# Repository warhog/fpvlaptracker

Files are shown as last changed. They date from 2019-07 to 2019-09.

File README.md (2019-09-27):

# fpvlaptracker

master: 

dev: 

licensed under [MIT](LICENSE.md)

open source diy fpv vtx lap tracking system

## features
- uses your analog vtx to do the lap detection
- 48 channels supported
- standalone (app) or connected mode (web frontend) available for single practicing or fun with friends
- connected mode supports up to 8 tracker units and comfortable access using web ui
- 2ms accuracy (tested with 4 parallel nodes)

## how does it work?
the tracker unit measures the video signal strength (rssi) of the selected video channel to detect laps using peak detection. it has a stand alone mode for single participants or a connected mode supporting multiple participants and a web ui. in standalone mode the tracker unit is controlled using bluetooth and a mobile app for configuration and single user race (e.g. practicing). the connected mode is used with any hardware that can run the java software backend.

### app
the tracker unit is accessed using bluetooth and a mobile application (older version was creating an wifi ap and serving a webpage but that was horrible slow). using the app one can configure the unit or run single user races (e.g. practicing).

the application is available in the play store (only android right now, [play store](https://play.google.com/store/apps/details?id=de.warhog.fpvlaptracker)), the source is in the app folder).

### standalone mode
the tracker can be used in standalone mode for single user races. only one tracker node and the app is needed.

### connected mode
running in the connected mode the tracker connects to a host software using wifi. races and particpants can be organized inside the host software. the host software includes a webserver that serves a web ui for watching / controlling races. one to multiple (max. 8) tracker nodes and server with wifi (e.g. raspi) required.

## tested devices
* immersion rc vtx
* blade inductrix fpv
* boscam ts5828
* eachine et526
* tbs unify pro hv
* betafpv 75s

## setup
[setup instructions](docs/setup.md)
    
## which hardware and software is used?
the hardware consists of a esp32 board with a boscam rx5808 receiver module connected. the esp32 runs the tracker firmware (written using Arduino software platform).
the backend of the race software for connected mode was written in java using spring boot 2. the frontend was developed using angular 8. the race software can be run on almost every platform that supports java se.
due to the low price, simplicity and size a raspberry pi (>= 2) powered by a power bank is the optimum solution for mobile usage.

# repository information
this repository contains everything needed to build your own tracker(s).

* app: the mobile app
* firmware: firmware for a single node
* hardware: hardware for a single node
* web: the java backend and web frontend for multiple node races

## sound files used
_lap:_ [freesound](https://www.freesound.org/people/StaneStane/sounds/73560/)

texts: [fromtexttospeech.com](http://www.fromtexttospeech.com/)

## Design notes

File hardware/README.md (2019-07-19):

# fpvlaptracker

this is the currently used hardware platform based on esp32 and rx5808.

for firmware building and flashing [read this](../docs/firmware.md)

## pictures

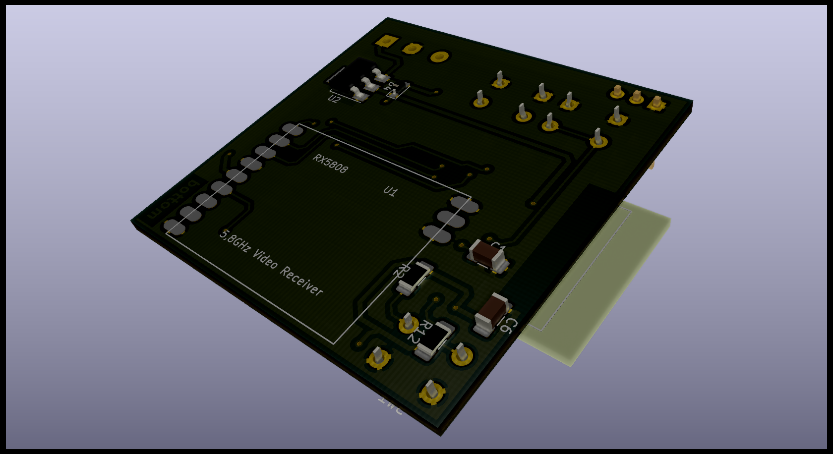
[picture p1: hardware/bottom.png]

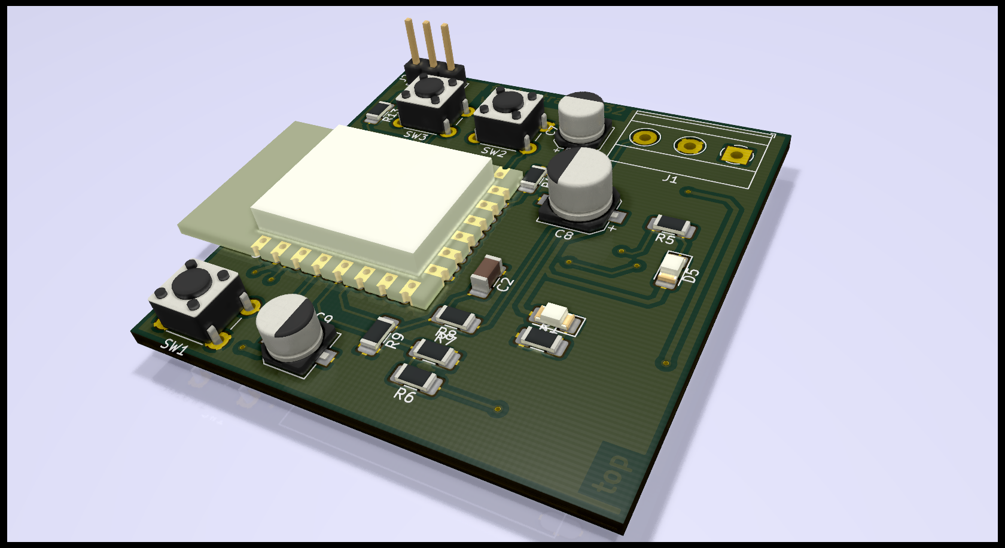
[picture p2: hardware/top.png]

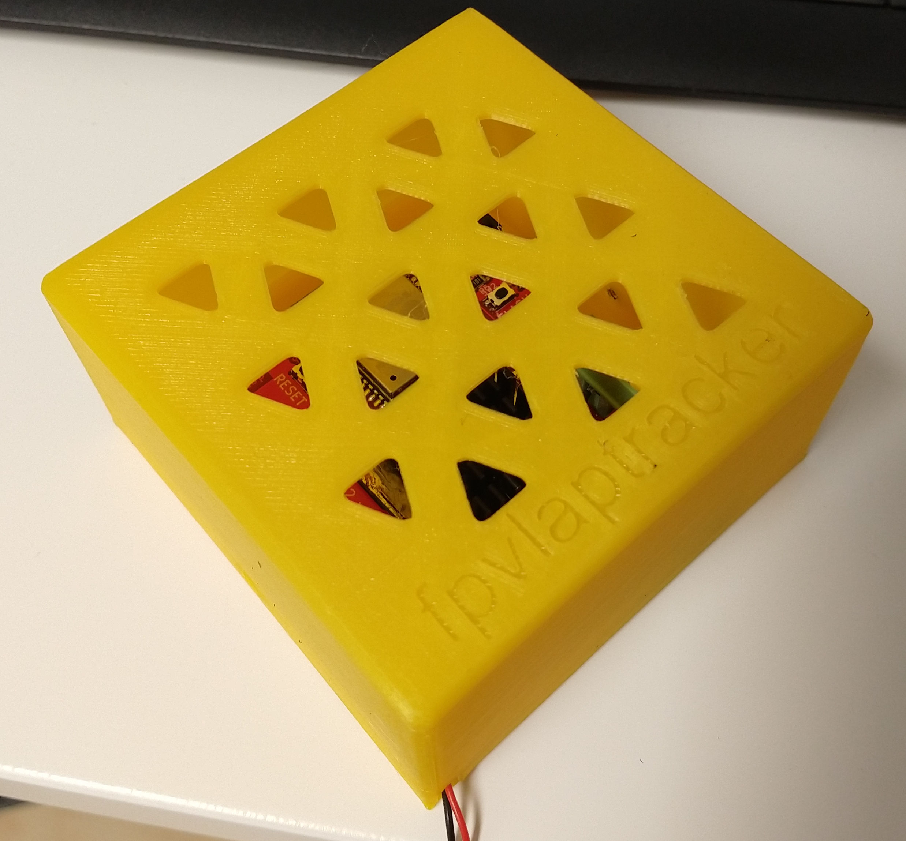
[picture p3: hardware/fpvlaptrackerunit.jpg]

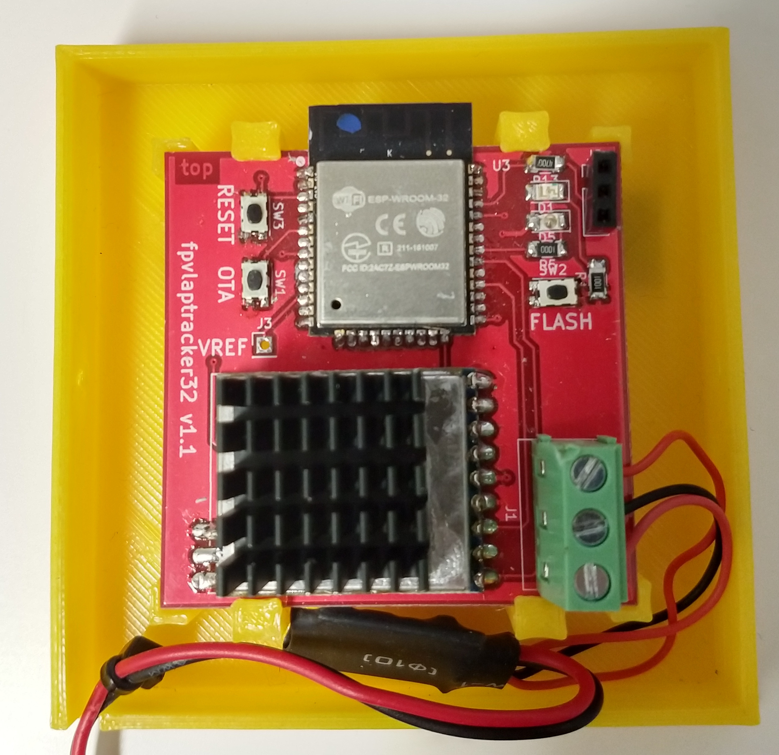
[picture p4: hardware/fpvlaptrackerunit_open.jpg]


## schematics
the schematics and pcb are drawn using KiCAD5 (see schematics folder).

[pdf schematics](https://raw.githubusercontent.com/warhog/fpvlaptracker/master/hardware/schematics/schematic.pdf)

## bom (bill of material)

most of the pcb parts are found in the [bom csv file](https://github.com/warhog/fpvlaptracker/blob/master/hardware/fpvlaptracker32-bom.csv).

some additional parts are needed optionally:
* heatsink with 20x20 mm and heatsink glue for the rx5808
* 5v power supply board if you want to power from a LiPo, ..., i used the [pololu D24V10F5](https://www.pololu.com/product/2831) for this.

## housing

there is a 3d printable housing availbe in the housing folder. printing in pla with 0.2 mm layer height is enough. no supports needed.

## gerber files

if you want to make your own pcb you can use the gerber files in the gerber folder. i've used itead and elecrow and both were fine (itead is a bit cheaper, elecrow was quicker).

## rx5808 5,8 GHz receiver mod
the rx5808 receiver needs to be modified to support the SPI protocol.
an excellent description by shea ivey can be found [here](https://github.com/sheaivey/rx5808-pro-diversity/blob/master/docs/rx5808-spi-mod.md).

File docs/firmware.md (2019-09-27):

# firmware

## usage

### startup
the node tries to connect to its configured wifi first. if the wifi is available it starts into connected mode and connects and registeres to the web ui. if the wifi is not available it goes into standalone mode using bluetooth.

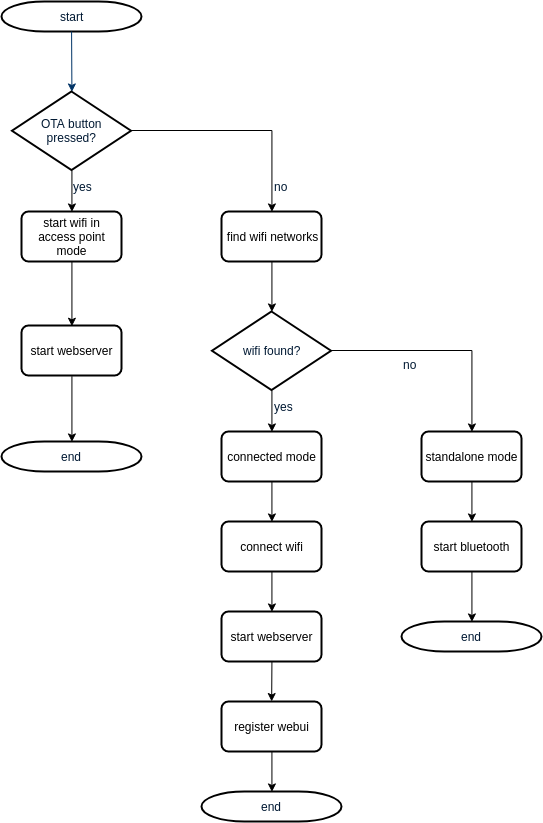
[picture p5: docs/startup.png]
flowchart startup


### leds
the leds show the state of the tracker node. the red led is showing if the 3.3v supply voltage is available. the green led shows different states of the tracker.

after connecting the supply voltage the green led blinks the number of cells detected (2 blinks = 2s, 3 blinks = 3s, ...).

the green led blinks very slow when in standalone mode. in connected mode the led is off.

the led can blink out error codes (quick pulses, longer pause):

| number of blinks | reason |
|---|---|
| 2 | bluetooth init failed |
| 3 | mDNS not started |
| 9 | shutdown voltage underrun |
| 10 | internal failure |

### buttons
there are 3 buttons on the node board:
* OTA
* RESET
* FLASH

3d printed case opened

#### RESET
the RESET button does....a reset :>

#### FLASH
the FLASH button initiates the serial update mode of the ESP32. to initate serial update mode do:
1. press and hold FLASH button
2. press RESET button
3. stop pressing RESET button
4. wait 1s
5. stop pressing FLASH button
6. the esp32 is now in serial update mode and can be flashed using a serial adapter (3.3v!)

#### OTA
when the OTA button is pressed during startup of the node it enteres wifi access point mode. this is useful to do a OTA update when base station is not available. the username and password is `fltunit`, the ip address is fixed to `192.168.4.1`.

### modes
the node can operate in standalone or connected mode. in standalone mode bluetooth is used to communicate with the mobile app. in connected mode wifi is used to communicate with the web ui.

### webpage
when in connected mode the node is configurable und usable using the web ui. also it provides a simple webpage. using this webpage one can
* switch to bluetooth mode
* trigger ota (over-the-air) update
* load factory defaults
* start voltage calibration

TODO: screenshot

### bluetooth
when in standalone mode the node is configurable and usable using the mobile app over bluetooth

## flashing
**do not interrupt power during flashing**

### using serial adapter
the easiest way is to use the esptool provided by espressif using python ([link to esptool documentation](https://github.com/espressif/esptool)).

to install esptool execute a pip install command in a command line / shell:

`pip install esptool`

now connect your 3.3v serial adapter to the node pcb.

> double check that your adapter is able to work with 3.3v! a 5v adapter might break your esp32!

TODO put picture here

1. connect ground pin of node to the ground pin of the serial adapter
2. connect rx pin of the node to the tx pin of the serial adapter
2. connect tx pin of the node to the rx pin of the serial adapter

to boot the node into serial flash mode follow the following procedure:
1. press and hold FLASH button
2. press RESET button
3. stop pressing RESET button
4. wait 1s
5. stop pressing FLASH button
6. the esp32 is now in serial update mode and can be flashed now

then run esptool with the following command:

`esptool --chip esp32 --port "[SERIAL_PORT]" --baud 921600  --before default_reset --after hard_reset write_flash -z --flash_mode qio --flash_freq 80 --flash_size detect 0x10000 "firmware-[VERSION].bin"`

* replace [SERIAL_PORT] with your serial port (e.g. COM4 for windows, /dev/ttyUSB0 or /dev/ttyACM5 on linux)
* replace [VERSION] with the firmware version you want to flash

### ota update
* start the node in connected mode or using the OTA button to start wifi ap (see OTA button description above)
* go to the webpage of the node (get ip from webui or 192.168.4.1 in wifi ap mode)
* select the .bin file you want to flash
* hit the update button
* wait some time, depending on the used browser it shows the upload state in bottom status bar
* after some time it should present a message with the status
* on success the node is restarted, verify the version using the webui or the node webpage

### voltage calibration
* start the node
* go to the node webpage
* hit voltage calibration link
* the node will output the voltage reference voltage on pin labeled VREF/J3
* connect a multimeter to the pin VREF/J3 on the pcb and ground
* get the voltage (should be between 999 and 1200 mV)
* reboot node
* goto webui node config or mobile app node config and set default voltage reference to the measured value

## building
the firmware uses the arduino stack. there is no restriction on IDE or anything. i used vscode with the arduino extension during development but use whatever is handy to you.

### prerequisites
install the esp32 sdk (i use 1.0.2)

install the following arduino libraries

|library|version|
|---|---|
|ArduinoJson|6.11.1|
|ResponsiveAnalogRead|1.2.1|

### target setup
* ESP32 dev module
* PSRAM: Disabled
* Partition Scheme: Minimal SPIFFS (1.9MB APP with OTA)
* CPU Frequency: 240 MHz
* Flash Mode: QIO
* Flash Frequency: 80 MHz
* Flash Size: 4MB (32Mb)
* Upload Speed: 921600
* Core Debug Level: None

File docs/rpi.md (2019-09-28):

# running fpvlaptracker in connected mode using a raspberry pi

the following descriptions explains the setup of a raspberry pi as base unit for multiple trackers running in connected mode.

i'm using a raspberry pi b3+ currently but a raspberry pi b2 also is working well. using the pi3 you can use the onboard wifi chipset.

pi4 was not tested yet but should also be working.

## setup wifi access point
the following guide will setup a wifi network called `flt-base` with password `flt-base`. the tracker nodes can automatically connect to it. you can also choose a different name and password but have to adjust it on the nodes using the mobile app then.

all the information (with only slight changes) regarding wifi setup was taken from [frillip.com](https://frillip.com/using-your-raspberry-pi-3-as-a-wifi-access-point-with-hostapd/). you can find further informations about the procedure there.

install dnsmasq and hostpad to provide access point mode and DHCP and DNS server
`sudo apt-get install dnsmasq hostapd`

setup a fixed ip address for your wifi interface.

open /etc/dhcpd.conf using `sudo nano /etc/dhcpcd.conf` and add at the bottom of the file `denyinterfaces wlan0`

open /etc/network/interfaces by using `sudo nano /etc/network/interfaces`

edit the `wlan0` section that it looks like follows
```allow-hotplug wlan0
iface wlan0 inet static
    address 172.24.1.1
    netmask 255.255.255.0
    network 172.24.1.0
    broadcast 172.24.1.255
#    wpa-conf /etc/wpa_supplicant/wpa_supplicant.conf
```

restart dhcpd and reload configuration for wlan0
```
sudo service dhcpcd restart
sudo ifdown wlan0; sudo ifup wlan0
```

configure hostapd by opening /etc/hostapd/hostapd.conf using `sudo nano /etc/hostapd/hostapd.conf`

put the following configuration in the config file
```# wifi interface to use
interface=wlan0

# Use the nl80211 driver with the brcmfmac driver
driver=nl80211

# This is the name of the network
ssid=flt-base

# Use the 2.4GHz band
hw_mode=g

# Use channel 6
channel=6

# Enable 802.11n
ieee80211n=1

# Enable WMM
wmm_enabled=1

# Enable 40MHz channels with 20ns guard interval
ht_capab=[HT40][SHORT-GI-20][DSSS_CCK-40]

# Accept all MAC addresses
macaddr_acl=0

# Use WPA authentication
auth_algs=1

# Require clients to know the network name
ignore_broadcast_ssid=0

# Use WPA2
wpa=2

# Use a pre-shared key
wpa_key_mgmt=WPA-PSK

# The network passphrase
wpa_passphrase=flt-base

# Use AES, instead of TKIP
rsn_pairwise=CCMP
```

open the default configuration file for hostapd using `sudo nano /etc/default/hostapd`, find the line `#DAEMON_CONF=""` and replace it with `DAEMON_CONF="/etc/hostapd/hostapd.conf"`.

open /etc/dnsmasq.conf by using `sudo nano /etc/dnsmasq.conf` and replace everything in the file with the following configuration:
```interface=wlan0      # Use interface wlan0
listen-address=172.24.1.1 # Explicitly specify the address to listen on
bind-interfaces      # Bind to the interface to make sure we aren't sending things elsewhere
server=8.8.8.8       # Forward DNS requests to Google DNS
domain-needed        # Don't forward short names
bogus-priv           # Never forward addresses in the non-routed address spaces.
dhcp-range=172.24.1.50,172.24.1.150,72h # Assign IP addresses between 172.24.1.50 and 172.24.1.150 with a 72 hour lease time
```

start the services
```sudo service hostapd start
sudo service dnsmasq start
```

you should now see a wifi network called `flt-base`. try to connect to it with password `flt-base`.

## install fpvlaptracker host software on the pi
using the automatic installation method the tracker software is installed in /home/pi/fpvlaptracker

1. connect the raspi to your local network (easiest by cable).
2. login to the raspi and issue the following wget to download the install shell script:
`https://raw.githubusercontent.com/warhog/fpvlaptracker/master/web/install.sh`
3. login to the pi and execute `install.sh` for automatic installation.
```chmod +x install.sh
./install.sh <version>
```
replace version with the version you like to install (see [github releases](https://github.com/warhog/fpvlaptracker/releases)).
4. after successful installation reboot the pi, connect to the wifi and call [`http://172.24.1.1`](http://172.24.1.1) in the browser of your choice.

## config file
you can set further options (like language for speech output) using the [config file](/docs/configuration.md) located in `/home/pi/fpvlaptracker/application.properties`

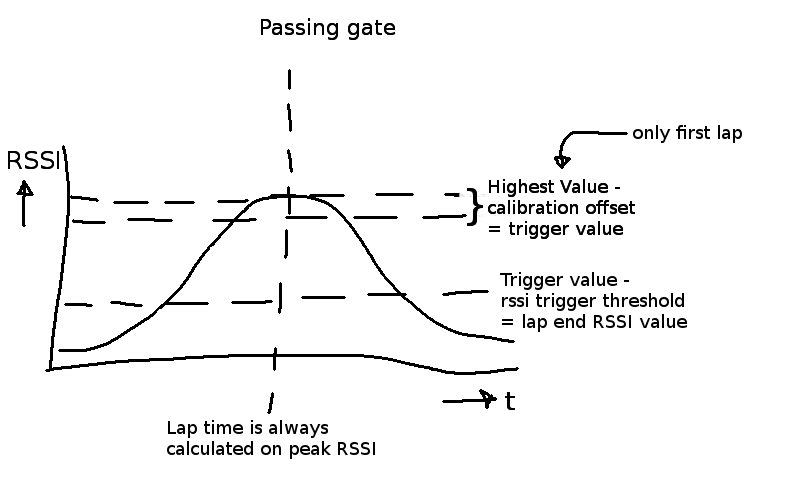
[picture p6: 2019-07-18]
app/src/assets/image/description.png

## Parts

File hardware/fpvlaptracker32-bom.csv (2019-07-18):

Id | Designator | Package | Quantity | Designation | Supplier and ref
1 | SW2 | SW_SPST_KMR2 | 1 | Prog | https://www.reichelt.de/smd-kurzhubtaster-4-2-x-2-8-mm-hoehe-1-9-mm-kmr-231-g-lfs-p148478.html?trstct=pos_0
2 | SW3 | SW_SPST_KMR2 | 1 | Reset | https://www.reichelt.de/smd-kurzhubtaster-4-2-x-2-8-mm-hoehe-1-9-mm-kmr-231-g-lfs-p148478.html?trstct=pos_0
3 | SW1 | SW_SPST_KMR2 | 1 | Webupdate | https://www.reichelt.de/smd-kurzhubtaster-4-2-x-2-8-mm-hoehe-1-9-mm-kmr-231-g-lfs-p148478.html?trstct=pos_0
4 | J1 | TerminalBlock_Phoenix_MKDS-1,5-3-5.08_1x03_P5.08mm_Horizontal | 1 | Screw_Terminal_01x03 | https://www.reichelt.de/loetbare-schraubklemme-3-pol-rm-5-08-mm-90-rnd-205-00233-p170278.html?
5 | U2 | SOT-223 | 1 | LM1117-3.3 | https://www.reichelt.de/ldo-spannungsregler-3-3-v-sot-223-lm-1117-mp-3-3-p187605.html?
6 | D4 | D_SOD-323_HandSoldering | 1 | DIODE | https://www.reichelt.de/gleichrichterdiode-75-v-0-15-a-sod-323f-1n-4148-ws-p95197.html?
7 | U1 | RX5808 | 1 | RX5808 | https://www.banggood.com/FPV-Wireless-Audio-Video-Receiving-Module-RX5808-Receiver-p-84775.html?rmmds=search
8 | C6,C1,C2 | C_1206_3216Metric_Pad1.42x1.75mm_HandSolder | 3 | 100nF | https://www.reichelt.de/smd-kerko-1206-100-nf-25-v-10-mlcc-rnd-150sh31b1043-p225567.html?
9 | R1,R9 | R_1206_3216Metric_Pad1.42x1.75mm_HandSolder | 2 | 1k | https://www.reichelt.de/smd-widerstand-1206-1-0-kohm-250-mw-1-rnd-1206-1-1-0k-p183379.html?
10 | R4 | R_1206_3216Metric_Pad1.42x1.75mm_HandSolder | 1 | 5k | https://www.reichelt.de/smd-widerstand-1206-5-1-kohm-250-mw-1-rnd-1206-1-5-1k-p183390.html?
11 | R6,R7,R8,R12,R2 | R_1206_3216Metric_Pad1.42x1.75mm_HandSolder | 5 | 10k | https://www.reichelt.de/smd-widerstand-1206-10-kohm-250-mw-1-rnd-1206-1-10k-p183394.html?
12 | R13 | R_1206_3216Metric_Pad1.42x1.75mm_HandSolder | 1 | 470 | https://www.reichelt.de/smd-widerstand-1206-470-ohm-250-mw-1-rnd-1206-1-470-p183358.html?
13 | U3 | ESP32-WROOM | 1 | ESP-32_WROOM32 | ebay, elecrow
14 | D1,D5 | LED_1206_3216Metric_Pad1.42x1.75mm_HandSolder | 2 | LED | https://www.reichelt.de/led-smd-1206-gruen-350-mcd-50-kbt-kptd-3216mg-p231716.html?
 |  |  |  |  | https://www.reichelt.de/led-smd-1206-rot-80-mcd-120-kbt-kp-3216src-p231712.html?
15 | C7,C9 | CP_Elec_5x4.4 | 2 | 10µF | https://www.reichelt.de/smd-chip-elko-10-f-16volt-smd-elko-10-16-p31906.html?
16 | C8 | CP_Elec_6.3x5.4 | 1 | 100µF | https://www.reichelt.de/smd-chip-elko-100-f-16volt-smd-elko-100-16-p31912.html?
17 | R5 | R_1206_3216Metric_Pad1.42x1.75mm_HandSolder | 1 | 100 | https://www.reichelt.de/smd-widerstand-1206-100-ohm-250-mw-1-rnd-1206-1-100-p183349.html?
18 | J2 | PinHeader_1x03_P2.54mm_Vertical | 1 | Serial | https://www.reichelt.de/20pol-buchsenleiste-gerade-rm-2-54-h-8-5mm-bl-1x20g8-2-54-p51827.html?trstct=pol_19
19 | J3 | PinHeader_1x01_P2.54mm_Vertical | 1 | Conn_01x01_Female | https://www.reichelt.de/20pol-buchsenleiste-gerade-rm-2-54-h-8-5mm-bl-1x20g8-2-54-p51827.html?trstct=pol_19

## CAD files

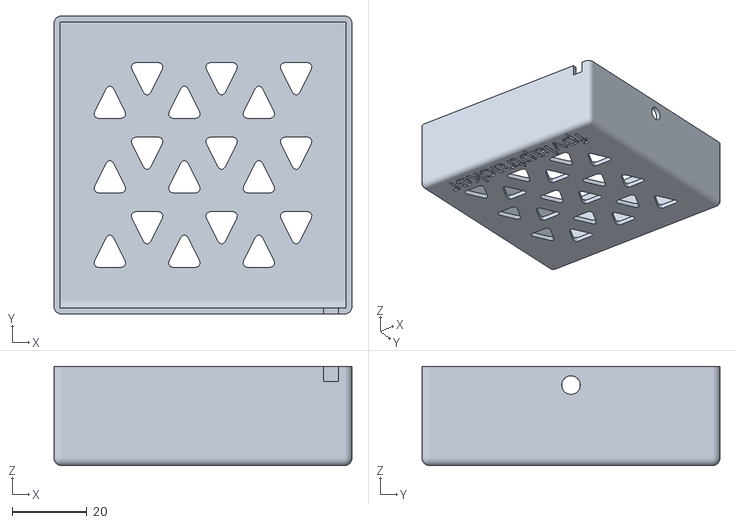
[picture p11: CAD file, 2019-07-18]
hardware/housing/fpvlaptracker32 case lid.stl
80.0 x 80.0 x 26.6

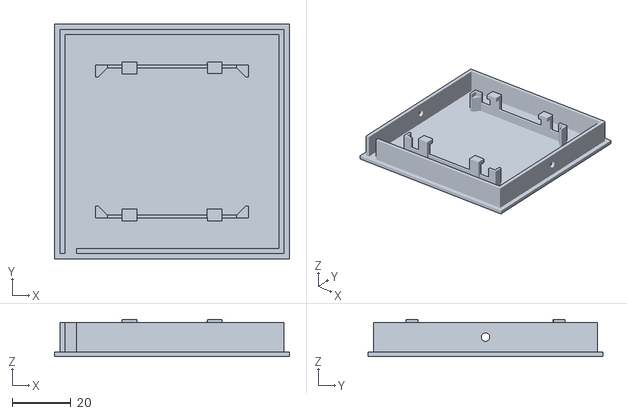
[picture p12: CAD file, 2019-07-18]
hardware/housing/fpvlaptracker32 case.stl
80.0 x 80.0 x 12.6

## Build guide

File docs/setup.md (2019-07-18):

# setup

## standalone or connected mode?
you can use the tracker unit in standalone or connected mode.

in standalone mode you use the mobile app to configure and/or start single user races.

in connected mode the tracker unit connects to the host system via wifi. there you can run multiple participant races with different race modes.

## nodes
tbd

## host software
you can run the host software on any computer and operating system that has java se support.

### raspberry pi
setup for raspberry pi setup is described here [raspberry pi  tutorial](rpi.md)

### computer 
just run the jar file from a command line (using java -jar fpvlaptracker-1.0.jar).

### configuration
the host software can be configured using a [config file](/docs/configuration.md).

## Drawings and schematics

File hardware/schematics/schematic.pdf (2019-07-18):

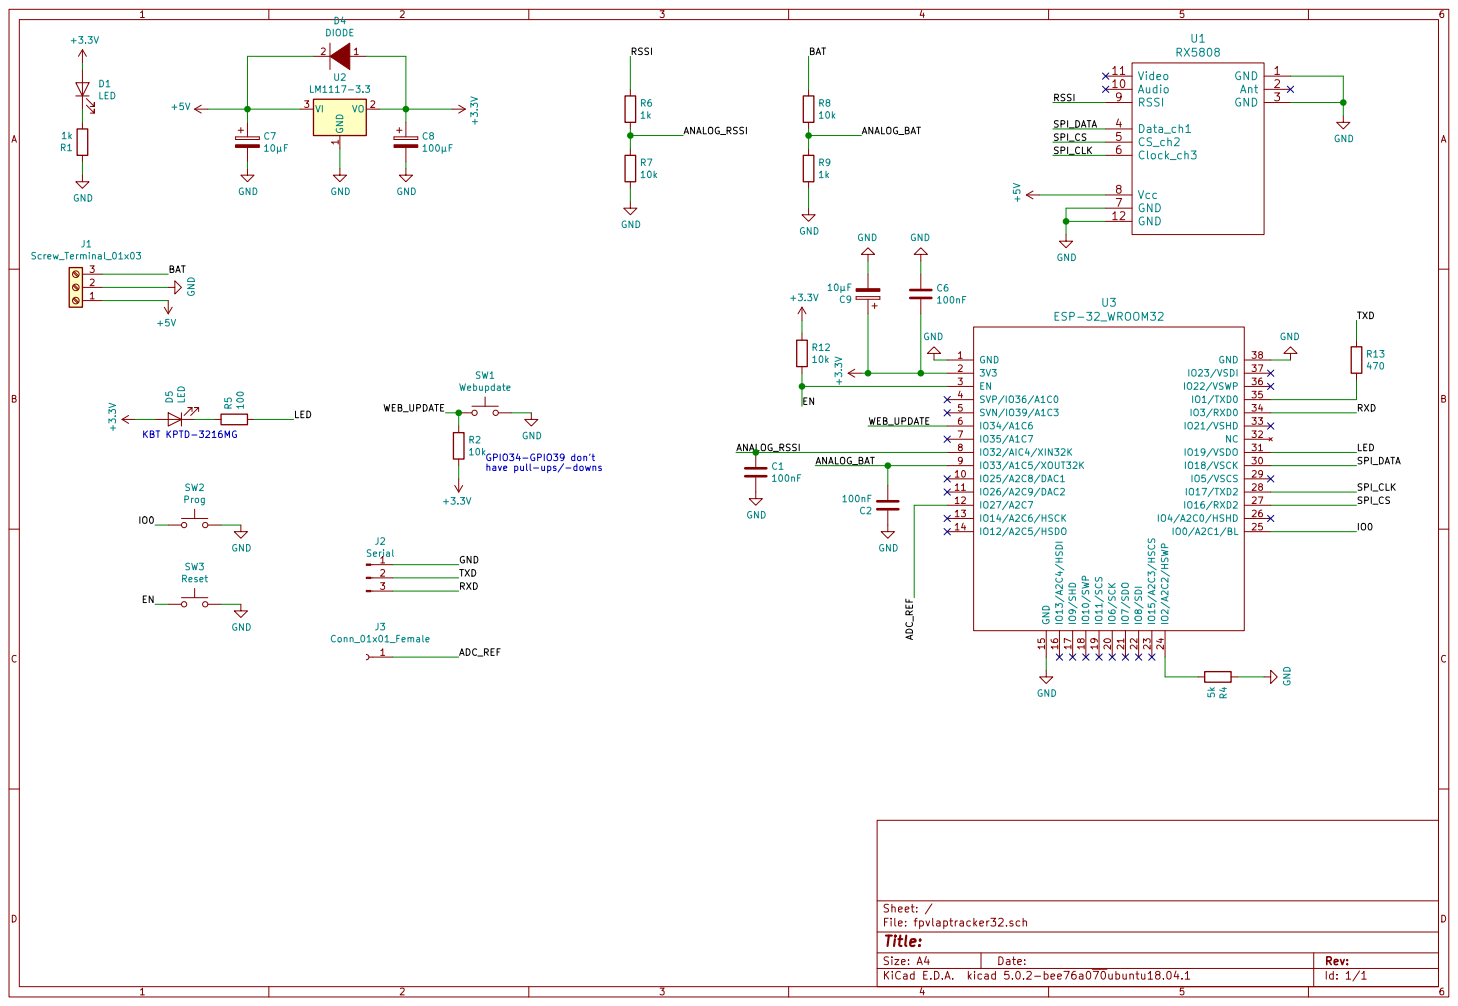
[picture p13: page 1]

GPIO34-GPIO39 don't have pull-ups/-downs 1

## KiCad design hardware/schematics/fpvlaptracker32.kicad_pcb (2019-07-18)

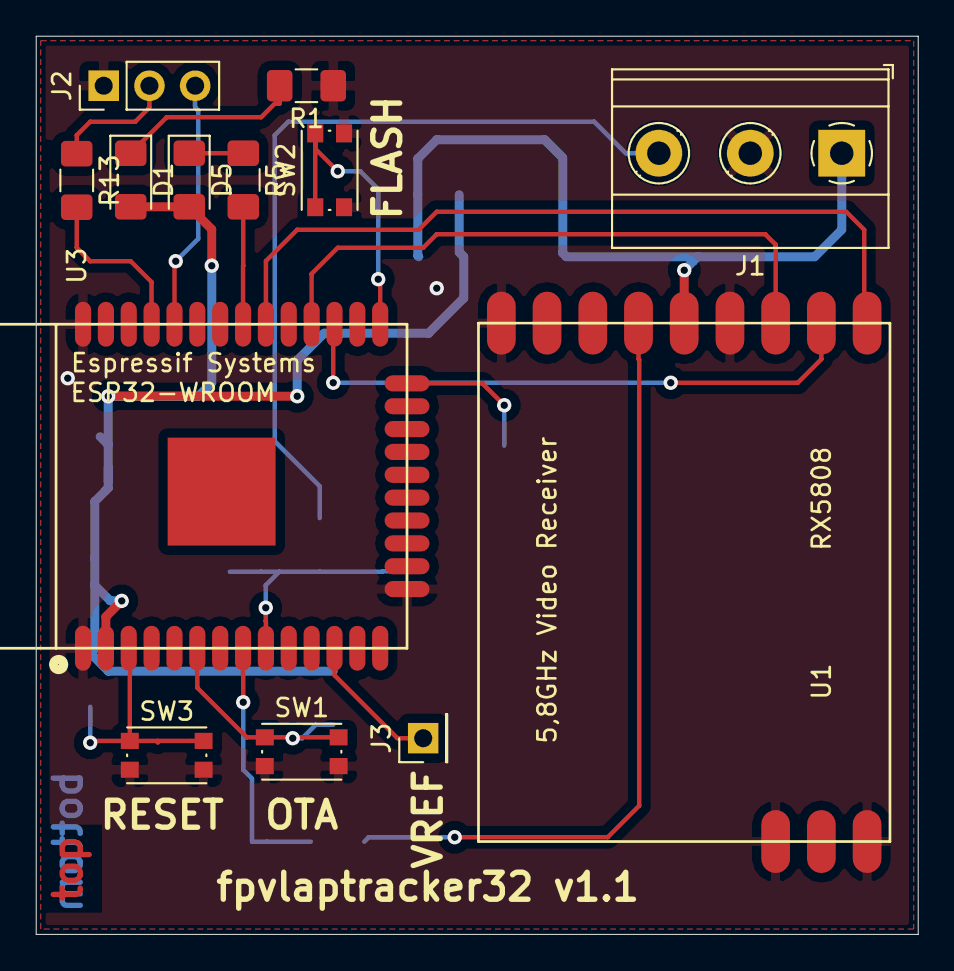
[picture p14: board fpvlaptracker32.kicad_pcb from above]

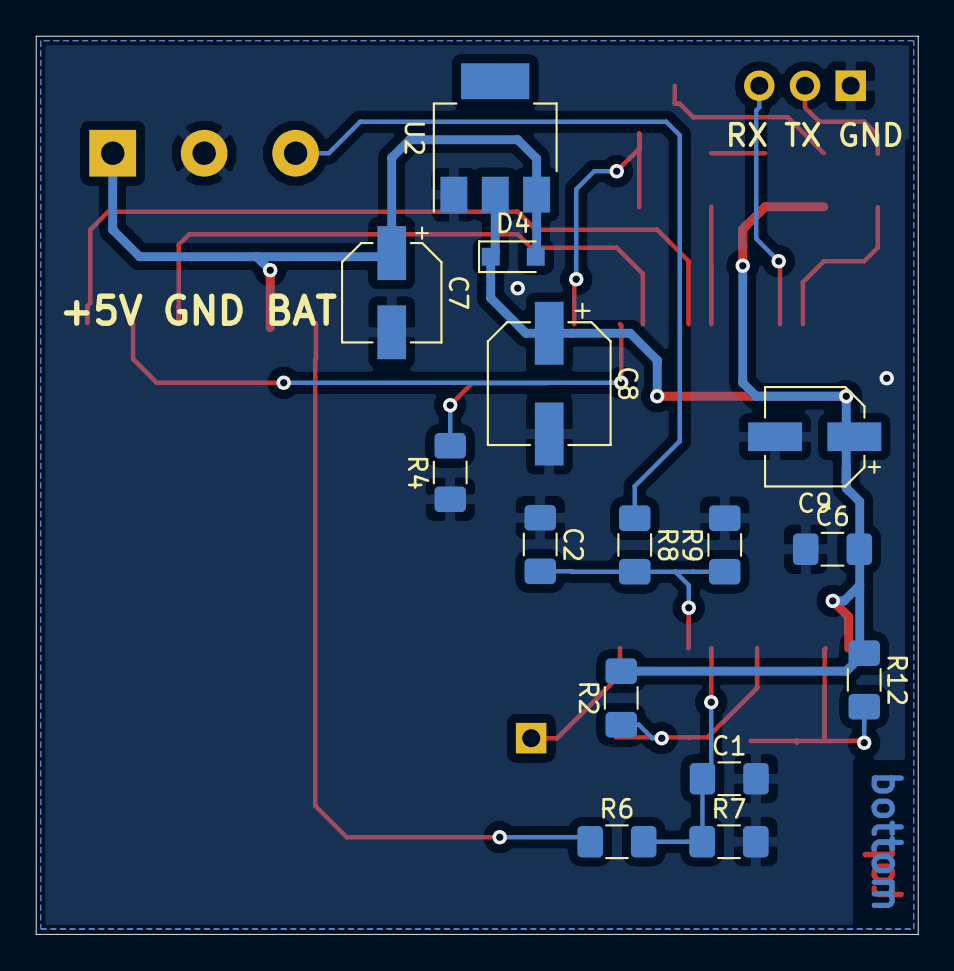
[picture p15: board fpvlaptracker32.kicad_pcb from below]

Board: 2 copper layers, 49.0 x 49.9 mm, 28 parts (15 on the bottom side), 21 nets.

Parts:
C1, C2, C6: 100nF; C_1206_3216Metric_Pad1.42x1.75mm_HandSolder
C7, C9: 10µF; CP_Elec_5x4.4
C8: 100µF; CP_Elec_6.3x5.4
D1, D5: LED; LED_1206_3216Metric_Pad1.42x1.75mm_HandSolder
D4: DIODE; D_SOD-323_HandSoldering
J1: Screw_Terminal_01x03; TerminalBlock_Phoenix_MKDS-1,5-3-5.08_1x03_P5.08mm_Horizont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
J2: Serial; PinHeader_1x03_P2.54mm_Vertical
J3: Conn_01x01_Female; PinHeader_1x01_P2.54mm_Vertical
R1, R9: 1k; R_1206_3216Metric_Pad1.42x1.75mm_HandSolder
R2, R6, R7, R8, R12: 10k; R_1206_3216Metric_Pad1.42x1.75mm_HandSolder
R4: 5k; R_1206_3216Metric_Pad1.42x1.75mm_HandSolder
R5: 100; R_1206_3216Metric_Pad1.42x1.75mm_HandSolder
R13: 470; R_1206_3216Metric_Pad1.42x1.75mm_HandSolder
SW1: Webupdate; SW_SPST_KMR2
SW2: Prog; SW_SPST_KMR2
SW3: Reset; SW_SPST_KMR2
U1: RX5808
U2: LM1117-3.3; SOT-223
U3: ESP-32_WROOM32; ESP32-WROOM

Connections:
+3V3: C6.2, C8.1, C9.1, D1.2, D4.1, D5.2, R2.2, R12.1, U2.2, U3.2
+5V: C7.1, D4.2, J1.1, U1.8, U2.3
/ADC_REF: J3.1, U3.12
/ANALOG_BAT: C2.2, R8.2, R9.1, U3.9
/ANALOG_RSSI: C1.1, R6.2, R7.1, U3.8
/BAT: J1.3, R8.1
/EN: R12.2, SW3.1, U3.3
/IO0: SW2.1, U3.25
/LED: R5.2, U3.31
/RSSI: R6.1, U1.9
/RXD: J2.3, U3.34
/SPI_CLK: U1.6, U3.28
/SPI_CS: U1.5, U3.27
/SPI_DATA: U1.4, U3.30
/TXD: J2.2, R13.1
/WEB_UPDATE: R2.1, SW1.1, U3.6
GND: C1.2, C2.1, C6.1, C7.2, C8.2, C9.2, J1.2, J2.1, R1.1, R4.1, R7.2, R9.2, SW1.2, SW2.2, SW3.2, U1.1, U1.3, U1.7, U1.12, U2.1, U3.1, U3.15, U3.38
unnamed: D1.1, R1.2
unnamed: D5.1, R5.1
unnamed: R4.2, U3.24
unnamed: R13.2, U3.35

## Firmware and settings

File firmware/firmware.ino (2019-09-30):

/*
 * fpvlaptracker32 firmware
 * fpv lap tracking software that uses rx5808 and esp32 to keep track of the fpv video signals
 * rssi for lap detection
 * 
 * 
 * the channel mapping tables are copied from shea iveys rx5808-pro-diversity project
 * https://github.com/sheaivey/rx5808-pro-diversity/blob/master/src/rx5808-pro-diversity/rx5808-pro-diversity.ino
 * 
 * the spi rx5808 code is taken from chickadee laptimer58 project
 * https://github.com/chickadee-tech/laptimer58
 * 
 * The MIT License (MIT)
 * 
 * Copyright (c) 2017-2019 warhog
 * 
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
 * 
 * 
 * blink codes:
 * fast blinking - standalone mode
 * no blinking - connected mode
 * blinking 2 times - BT init failed
 * blinking 3 times - mdns not started
 * blinking 4 times - wifi ap cannot be started
 * blinking 9 times - shutdown voltage
 * blinking 10 times - internal failure
 * 
 */
#include <EEPROM.h>
#include <BluetoothSerial.h>
#include <ESPmDNS.h>
#include <WiFi.h>

#include "rssi.h"
#include "lapdetector.h"
#include "ledcontrol.h"
#include "storage.h"
#include "wificomm.h"
#include "btcomm.h"
#include "frequency.h"
#include "rx5808.h"
#include "statemanager.h"
#include "batterymgr.h"
#include "wifiwebserver.h"
#include "wifiap.h"
#include "commtools.h"

// debug mode flags
//#define DEBUG
//#define MEASURE

// pin configurations
const unsigned int PIN_SPI_SLAVE_SELECT = 16;
const unsigned int PIN_SPI_CLOCK = 17;
const unsigned int PIN_SPI_DATA = 18;
const unsigned int PIN_LED = 19;
const unsigned int PIN_ANALOG_RSSI = 32;
const unsigned int PIN_WEB_UPDATE = 34;
const unsigned int PIN_ANALOG_BATTERY = 33;

lap::Rssi rssi(PIN_ANALOG_RSSI);
ledio::LedControl led(PIN_LED);
util::Storage storage;
lap::LapDetector lapDetector(&storage, &rssi);
radio::Rx5808 rx5808(PIN_SPI_CLOCK, PIN_SPI_DATA, PIN_SPI_SLAVE_SELECT, PIN_ANALOG_RSSI);
BluetoothSerial btSerial;
battery::BatteryMgr batteryMgr(PIN_ANALOG_BATTERY, &storage);
statemanagement::StateManager stateManager;
unsigned long loopTime = 0L;
unsigned long lastLoopTimeRun = 0L;
comm::WifiWebServer wifiWebServer(&storage, &rssi, &rx5808, &lapDetector, &batteryMgr, &stateManager, &loopTime);
comm::WifiComm wifiComm(&storage, &rssi, &rx5808, &lapDetector, &batteryMgr, &stateManager, &loopTime);
comm::BtComm btComm(&btSerial, &storage, &rssi, &rx5808, &lapDetector, &batteryMgr, &stateManager, &wifiComm, &loopTime);
comm::WifiAp wifiAp;
unsigned long rssiTimeout = 0L;
unsigned long lowVoltageTimeout = 0L;

void wifiConnect();
void bluetoothConnect();
void blinkError(unsigned int errorCode);

/*---------------------------------------------------
 * application setup
 *-------------------------------------------------*/
void setup() {
	led.off();
#if defined(DEBUG) || defined(MEASURE)
	Serial.begin(115200);
	Serial.println("");
	Serial.println("");
#ifdef DEBUG
	Serial.println(F("booting"));
    Serial.printf("Chip ID: %s\n", comm::CommTools::getChipIdAsString().c_str());
#endif
#ifdef MEASURE
	Serial.println(F("INFO: running measure mode"));
#endif
	Serial.flush();
#endif

	randomSeed(analogRead(PIN_ANALOG_BATTERY));

#ifdef DEBUG
	Serial.println(F("setting up ports"));
#endif
	rx5808.init();
	pinMode(PIN_WEB_UPDATE, INPUT_PULLUP);
	if (digitalRead(PIN_WEB_UPDATE) == LOW) {
#ifdef DEBUG
		Serial.println(F("force wifi ap mode"));
#endif
		if (!wifiAp.connect()) {
#ifdef DEBUG
			Serial.println(F("cannot enable wifi ap mode"));
#endif
			blinkError(4);
		}
	}

#ifdef DEBUG
	Serial.println(F("reading config from eeprom"));
#endif
	EEPROM.begin(512);
	storage.load();

#ifdef DEBUG
	Serial.println(F("setup batterymgr"));
#endif
	batteryMgr.detectCellsAndSetup();
#ifdef DEBUG
	Serial.printf("alarmVoltage: %f, shutdownVoltage: %f\n", batteryMgr.getAlarmVoltage(), batteryMgr.getShutdownVoltage());
#endif
	// blink <cell number> of times to give feedback on number of connected battery cells and signal startup
	led.mode(ledio::modes::BLINK_SEQUENCE);
	led.blinkSequence(batteryMgr.getCells(), 15, 250);
	for (unsigned int i = 0; i < ((250 + 15) * batteryMgr.getCells()); i++) {
		led.run();
		delay(1);
	}
	led.off();

	lapDetector.init();

#ifdef DEBUG
	Serial.println(F("setting radio frequency"));
#endif
	rx5808.freq(storage.getFrequency());
#ifdef DEBUG
	Serial.print(F("channel info: "));
	Serial.print(storage.getFrequency());
	Serial.print(F(" MHz, "));
	Serial.println(freq::Frequency::getChannelNameForFrequency(storage.getFrequency()));
#endif

	if (wifiAp.isConnected()) {
		wifiWebServer.begin();
	} else {
		// try to connect to wifi, if ssid not found, start bluetooth
		wifiConnect();
	}

	// no wifi found, start bluetooth
	if (!wifiComm.isConnected() && !wifiAp.isConnected()) {
		bluetoothConnect();
		if (btComm.isConnected()) {
			led.blinkSequence(UINT_MAX, 125, 2000);
			led.mode(ledio::modes::BLINK_SEQUENCE);
		}
	}

	if (wifiWebServer.isConnected()) {
#ifdef DEBUG
		Serial.println(F("setting up mdns"));
#endif
		String mdnsName = "flt-unit-";
		mdnsName += comm::CommTools::getChipIdAsString();
		if (!MDNS.begin(mdnsName.c_str())) {
#ifdef DEBUG
			Serial.println(F("error setting up MDNS responder!"));
#endif
			blinkError(3);
		}
		MDNS.addService("http", "tcp", 80);
	}

#ifdef DEBUG
	Serial.println(F("entering main loop"));
#endif
}

/*---------------------------------------------------
 * application main loop
 *-------------------------------------------------*/
void loop() {

	batteryMgr.measure();
	if (batteryMgr.isShutdown()) {
#ifdef DEBUG
		Serial.println(F("voltage isShutdown"));
#endif
		blinkError(9);
	} else if (batteryMgr.isAlarm() && millis() > lowVoltageTimeout) {
		// undervoltage warning
#ifdef DEBUG
		Serial.println(F("voltage isAlarm"));
#endif
		lowVoltageTimeout = millis() + (30 * 1000);
		if (btComm.isConnected() && btComm.hasClient()) {
#ifdef DEBUG
			Serial.println(F("bt voltage sendAlarm"));
#endif
			btComm.sendVoltageAlarm(batteryMgr.getVoltage());
		}
		if (wifiComm.isConnected()) {
#ifdef DEBUG
			Serial.println(F("wifi voltage sendAlarm"));
#endif
			wifiComm.sendVoltageAlarm(batteryMgr.getVoltage());
		}
	}

	led.run();
	
	rssi.process();
#ifdef MEASURE
	Serial.print(F("VAR: rssi="));
	Serial.println(rssi.getRssi());
#endif

	if (stateManager.isStateStartup()) {
#if defined(DEBUG) || defined(MEASURE)
		Serial.println(F("STATE: STARTUP"));
#endif
		stateManager.update(statemanagement::state_enum::CALIBRATION);
		lapDetector.enableCalibrationMode();
		rssi.setFilterRatio(storage.getFilterRatioCalibration());
#ifdef DEBUG
		Serial.println(F("switch to calibration mode"));
#endif
	} else if (stateManager.isStateDeepscan()) {
		rx5808.scan();
		if (rx5808.isScanDone()) {
			// scan is done, start over
			unsigned int currentFrequency = rx5808.getScanFrequency();
			if (btComm.isConnected()) {
				btComm.sendScanData(currentFrequency, rx5808.getScanResult());
			} else if (wifiComm.isConnected()) {
				wifiComm.sendScanData(currentFrequency, rx5808.getScanResult());
			}
			currentFrequency++;
			if (currentFrequency >= freq::HIGHEST_FREQUENCY) {
				currentFrequency = freq::LOWEST_FREQUENCY;
			}
			rx5808.startScan(currentFrequency);
		}
	} else if (stateManager.isStateScan()) {
		rx5808.scan();
		if (rx5808.isScanDone()) {
			// scan is done, start over
			int currentChannel = rx5808.getScanChannel();
			if (currentChannel != 65535) {
				if (btComm.isConnected()) {
					btComm.sendScanData(freq::Frequency::getFrequencyForChannelIndex(currentChannel), rx5808.getScanResult());
				} else if (wifiComm.isConnected()) {
					wifiComm.sendScanData(freq::Frequency::getFrequencyForChannelIndex(currentChannel), rx5808.getScanResult());
				}
			}
			currentChannel++;
			if (currentChannel >= freq::NR_OF_FREQUENCIES) {
				currentChannel = 0;
			}
			rx5808.setScanChannel(currentChannel);
			rx5808.startScan(freq::Frequency::getFrequencyForChannelIndex(currentChannel));
		}
	} else if (stateManager.isStateCalibration()) {
#ifdef MEASURE
		Serial.println(F("STATE: CALIBRATION"));
#endif
		if (lapDetector.process()) {
#ifdef MEASURE
			Serial.println(F("INFO: lap detected, calibration is done"));
#endif
			stateManager.update(statemanagement::state_enum::CALIBRATION_DONE);
		}
	} else if (stateManager.isStateCalibrationDone()) {
#if defined(DEBUG) || defined(MEASURE)
		Serial.println(F("STATE: CALIBRATION_DONE"));
#endif
		if (btComm.isConnected()) {
			btComm.sendCalibrationDone();
		}
		if (wifiComm.isConnected()) {
			wifiComm.sendCalibrationDone();
		}
		rssi.setFilterRatio(storage.getFilterRatio());
		stateManager.update(statemanagement::state_enum::RACE);
	} else if (stateManager.isStateRace()) {
#ifdef MEASURE
		Serial.println(F("STATE: RACE"));
#endif
		if (lapDetector.process()) {
#ifdef MEASURE
			Serial.println(F("INFO: lap detected"));
			Serial.print(F("VAR: lastlaptime="));
			Serial.println(lapDetector.getLastLapTime());
			Serial.print(F("VAR: lastlaprssi="));
			Serial.println(lapDetector.getLastLapRssi());
#endif
			led.oneshot();
			if (wifiComm.isConnected()) {
				wifiComm.lap(lapDetector.getLastLapTime(), lapDetector.getLastLapRssi());
			}
			if (btComm.isConnected()) {
				btComm.lap(lapDetector.getLastLapTime(), lapDetector.getLastLapRssi());
			}
#ifdef DEBUG
			Serial.println(F("lap detected"));
			Serial.print(F("rssi="));
			Serial.println(lapDetector.getLastLapRssi());
			Serial.print(F("laptime="));
			Serial.println(lapDetector.getLastLapTime());
#endif
		}
	} else if (stateManager.getState() == statemanagement::state_enum::SWITCH_TO_BLUETOOTH) {
		if (wifiWebServer.isConnected()) {
			wifiWebServer.disconnect();
		}
		if (wifiComm.isConnected()) {
			wifiComm.disconnect();
		}
		if (wifiAp.isConnected()) {
			wifiAp.disconnect();
		}
		bluetoothConnect();
		stateManager.update(statemanagement::state_enum::RESTORE_STATE);
	} else if (stateManager.getState() == statemanagement::state_enum::VREF_OUTPUT) {
		if (wifiWebServer.isConnected()) {
			wifiWebServer.disconnect();
		}
		if (wifiComm.isConnected()) {
			wifiComm.disconnect();
		}
		if (wifiAp.isConnected()) {
			wifiAp.disconnect();
		}
		if (btComm.isConnected()) {
			btComm.disconnect();
		}
		batteryMgr.enableVrefOutput();
	} else if (stateManager.isStateError()) {
#ifdef MEASURE
		Serial.println(F("STATE: ERROR"));
#endif
	} else {
		blinkError(10);
	}

	if (millis() >= rssiTimeout && (stateManager.isStateCalibration() || stateManager.isStateRace())) {
		rssiTimeout = millis() + 500;
		if (btComm.isConnected()) {
			btComm.sendRssiData(rssi.getRssi());
		} else if (wifiComm.isConnected()) {
			wifiComm.sendRssiData(rssi.getRssi());
		}
	}

	if (wifiComm.isConnected()) {
		// if we are in network mode, process udp
		wifiComm.processIncomingMessage();
	} else if (btComm.isConnected()) {
		// in bluetooth mode process the incoming bluetooth serial data
		btComm.processIncomingMessage();
	}

	if (wifiWebServer.isConnected()) {
		// handle the wifi webserver data
		wifiWebServer.handle();
	}

	loopTime = micros() - lastLoopTimeRun;
	lastLoopTimeRun = micros();
}

void bluetoothConnect() {
#ifdef DEBUG
	Serial.println(F("connecting bluetooth"));
#endif
	int bterr = btComm.connect();
	if (bterr != comm::btErrorCode::OK) {
#ifdef DEBUG
		Serial.print(F("bt module error: "));
		Serial.println(bterr);
#endif
		if (bterr == comm::btErrorCode::INIT_FAILED) {
			blinkError(2);
		}
	}
#ifdef DEBUG
	Serial.println(F("bluetooth connected"));
#endif
}

void wifiConnect() {
#ifdef DEBUG
	Serial.println(F("connecting wifi"));
#endif
	wifiComm.connect();
	if (wifiComm.isConnected()) {
#ifdef DEBUG
		Serial.println(F("wifi connected, starting node registration"));
#endif
		wifiComm.reg();
#ifdef DEBUG
		Serial.println(F("node registration done, starting webserver"));
#endif
		wifiWebServer.begin();
#ifdef DEBUG
		Serial.println(F("webserver started"));
	} else {
		Serial.println(F("wifi not connected"));
#endif
	}
}

/*---------------------------------------------------
 * error code blinker
 *-------------------------------------------------*/
void blinkError(unsigned int errorCode) {
#ifdef DEBUG
	Serial.print(F("error code: "));
	Serial.println(errorCode);
	Serial.flush();
#endif
	led.mode(ledio::modes::STATIC);
	while (true) {
		for (int i = 0; i < errorCode; i++) {
			led.on();
			delay(100);
			led.off();
			delay(200);
		}
		delay(1000);
	}
}

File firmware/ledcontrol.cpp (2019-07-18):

#include "ledcontrol.h"

using namespace ledio;

LedControl::LedControl(const int pin) : _pin(0), _mode(modes::STATIC), _interval(1000L), _nextRun(0L),
    _blinkSequenceCount(0L), _blinkSequenceLength(0L), _blinkSequenceWait(0L), _blinkSequenceState(0) {
    this->_pin = pin;
    pinMode(this->_pin, OUTPUT);
    this->off();
}

void LedControl::toggle() {
    digitalWrite(this->_pin, !digitalRead(this->_pin));
}

void LedControl::off() {
    digitalWrite(this->_pin, HIGH);
}

void LedControl::on() {
    digitalWrite(this->_pin, LOW);
}

void LedControl::mode(modes mode) {
    if (this->_mode != mode) {
        if (mode == modes::OFF) {
            this->off();
        } else if (mode == modes::STATIC) {
            this->on();
        } else if (mode == modes::BLINK_SEQUENCE) {
            this->_blinkSequenceState = 0;
            this->off();
            this->scheduleNextRun(0L);
        }
    }
    this->_mode = mode;
}

void LedControl::blinkSequence(unsigned int count, unsigned long length, unsigned long wait) {
    this->_blinkSequenceCount = count;
    this->_blinkSequenceLength = length;
    this->_blinkSequenceWait = wait;
    this->_blinkSequenceState = 0;
    this->off();
    this->scheduleNextRun(0L);
}

bool LedControl::blinkSequenceDone() {
    return this->_blinkSequenceState == UINT_MAX;
}

void LedControl::run() {
    if (this->_mode == modes::BLINK) {
        if (this->isExpired()) {
            this->scheduleNextRun(this->_interval);
            this->toggle();
        }
    } else if (this->_mode == modes::BLINK_SEQUENCE) {
        if (this->isExpired()) {
            if (this->_blinkSequenceState == 0) {
                this->_blinkSequenceState++;
                this->on();
                this->scheduleNextRun(this->_blinkSequenceLength);
            } else if (this->_blinkSequenceState >= (this->_blinkSequenceCount * 2)) {
                this->_mode = modes::OFF;
                this->_blinkSequenceState = 0;
                this->_blinkSequenceState = UINT_MAX;
                this->off();
            } else {
                this->_blinkSequenceState++;
                if (this->_blinkSequenceState % 2 == 0) {
                    // state is even
                    this->on();
                    this->scheduleNextRun(this->_blinkSequenceLength);
                } else {
                    // state is odd
                    this->off();
                    this->scheduleNextRun(this->_blinkSequenceWait);
                }
            }
        }
    }
}

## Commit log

2017-08-15 added hardware folder, added stl files for case
    [fpvlaptracker case lid.stl, fpvlaptracker case.stl]
2017-08-22 added schematics and eagle files
    [flt.brd, flt.sch]
2018-06-30 added serial communication to app, improved bt init on soft reset, made frequency class singleton
    [btcomm.cpp]
2018-07-10 added trace tool set connected to false on startup
2018-08-13 added calibration done message
2018-08-24 added battery adc
2018-08-24 improved dataexchange, small fixes
    [btcomm.cpp]
2018-08-25 introduced batterymanager
2018-08-25 start battery measurement on startup
2018-08-25 removed publisher/subscriber and replaced with pointers to statemanager
    [btcomm.cpp]
2018-08-26 new defaults for trigger threshold and calibration offset
2018-09-09 changed chipid to long to match esp32 chipid
2018-09-12 added calibrationdone packet type
2018-09-13 small fixes, addition of devicedata for esp32 unit
2018-09-13 removed hardware files
    [flt.brd, flt.sch, fpvlaptracker case lid.stl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]
2018-09-13 added calibration done audio message
2018-10-03 full esp32 tracker support
2018-10-13 added udp thread status, added favicon
2018-12-19 reorder items, add cell voltage
2018-12-22 add battery shutdown voltage message
2018-12-23 make permanent switchable for danger alerts
2019-03-08 added skip calibration feature
2019-03-08 set skip calibration button style
2019-03-08 added rssi text, fixed small issues with calibration skipping
2019-03-08 prepared lap invalidity, improve switching of race type
2019-03-10 change race mode using buttons instead ofselect
2019-03-10 added profile apply button
2019-03-22 lots of fixes and improvments, added ledservice
2019-07-18 combined single repos back into one repo
    [fpvlaptracker32 case lid.stl, fpvlaptracker32 case.stl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]
2019-07-18 added prototypes
2019-07-18 changed folder names
    [fpvlaptracker32 case lid.stl, fpvlaptracker32 case.stl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]
2019-07-19 switch to gulp-inject-version2
2019-08-25 fix rssi packet issue, added overlay to update, added ssid+password to data
    [btcomm.cpp]
2019-09-01 fix length of alerts on mobile devices
2019-09-01 fix fullscreen in device view, fix issue when no tracker selected
2019-09-27 print env variables
2019-09-27 improve wifi ap mode naming and error handling, fix mdns http register being too early, improve node webui
    [firmware.ino, wifiap.cpp, wifiwebserver.cpp]
2019-09-27 fix reboot from ui
    [wifiwebserver.cpp]
2019-09-28 added rssi to node web ui improved version commit on node web ui changed web ui calls to node to /api added node factory defaults for webui fix nodesetup webui redirector change log level to info all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
    [wifiwebserver.cpp]
2019-09-30 fix bluetooth switch wrong link on node ui
    [wifiwebserver.cpp]
2019-09-30 fix debug message text
    [firmware.ino]
2019-10-01 made audio language switchable using webui
2019-10-01 fix wifi ap mode
    [wifiap.cpp]
